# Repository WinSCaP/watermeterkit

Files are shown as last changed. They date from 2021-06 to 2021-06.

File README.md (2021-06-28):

# watermeterkit

> Maak je even een backup van je Wemos? :)
- Download https://github.com/espressif/esptool
- backup `.\esptool.exe --port COMx --baud 115200 read_flash 0x000 4194304 backup-watermeter.bin` (Eigen COM poort opgeven)
- restore `.\esptool.exe --port COMx --baud 115200 write_flash 0x000 backup-watermeter.bin`
- Heb je python? [espota.py](https://github.com/esp8266/Arduino/blob/master/tools/espota.py)
- `python espota.py -d -i 192.168.4.1 -f backup-watermeter.bin` (OTA, dus niet naar de meterkast om te flashen )

De watermeterkit kun je kopen via watermeterkit.nl. Deze is compleet met behuizing. Maar helaas is er ook een nadeel. De YAML is niet vrijgegeven, dus hij is defacto closed source. Maar daar kunnen we iets aan doen :)

## Ja en nu?
1. De YAML voor model A en model B vind je [hier](esphome)
2. Wil je een generieke [behuizing](mount)
3. Of gewoon de [home assistant config?](homeassistant)

### Kosten voor water in HA
Tarieven:
- [Dunea](https://www.dunea.nl/tarieven-en-voorwaarden)
- Pull requests welkom :)

## Reverse enginering Model B
- NPN Proximity Sensor LJ18A3-8-Z/BX-5V (https://nl.aliexpress.com/item/32844213899.html)
  - 5v Bruin
  - gnd blauw
  - data zwart (D5)
- WemosD1 (https://nl.aliexpress.com/item/32651747570.html)
- RGB Led (blauw niet aan Wemos)
  - D4 - Rood
  - D3 - Groen (zit ook aan standaard blauwe LED van Wemos)
  - Vervangen door Neopixel? (https://nl.aliexpress.com/item/32732638750.html)
- HDC1080 (temperature humidity) Component in ESPhome
  - Model A heeft een SHT
  - BME 280 toevoegen voor luchtdruk?
- Additioneel
  - Buzzer (Restant van Tagreader (https://github.com/adonno/tagreader) D7?

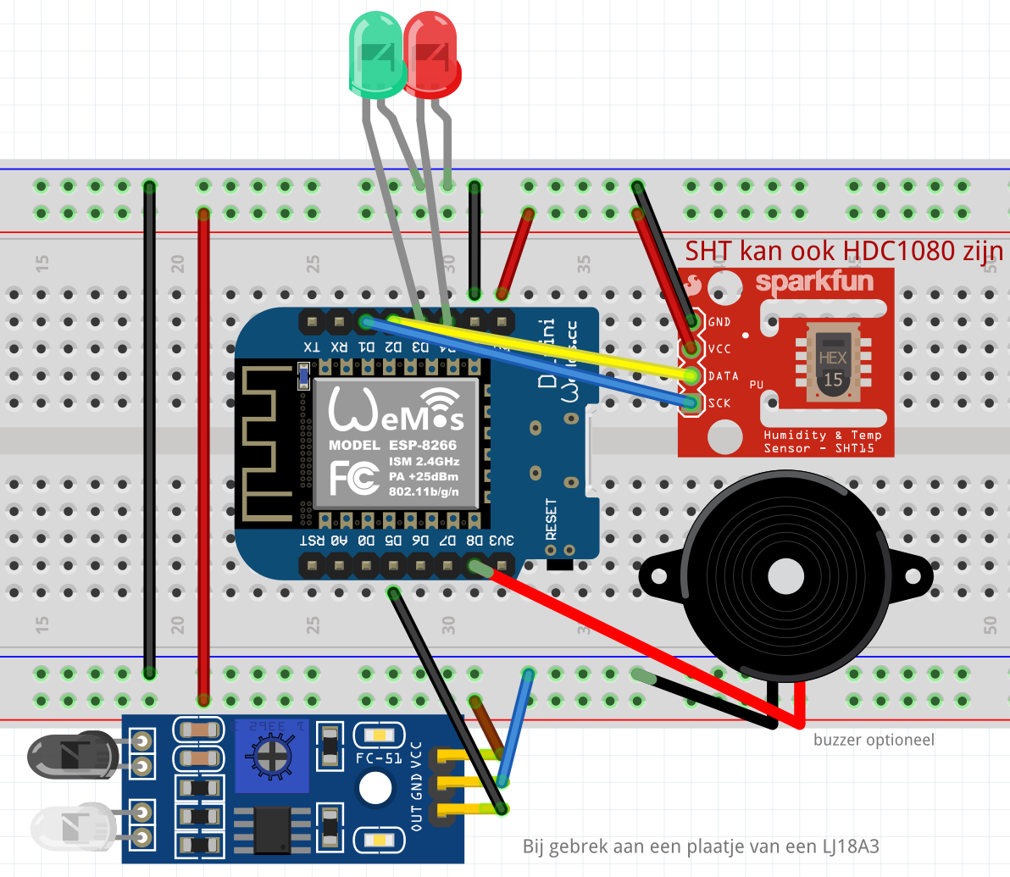
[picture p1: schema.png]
Schema


| | | Wemos  | | |
|---|---|---|---|---|
| |RST| |TX | |
| |A0| |RX | |
| |D0| |D1 |HDC1080 - SCL|
|Pulsemeter|D5| |D2 |HDC1080 - SDA|
| |D6| |D3 |Led G|
| |D7| |D4 |Led R|
| |D8| |GND| |
| |3v3| |5V| |

## Mounts
- Sensus 620 https://www.thingiverse.com/thing:4489072
- Generiek (In deze Repo)
- Kopen bij watermeterkit.nl
 
## Meuk
- https://www.jbswebcom.nl/knutselen/index.php/watermeter-uitlezen-met-npn-sensor
- https://community.home-assistant.io/t/inductive-npn-sensor-and-raspberry-pi/132487
- https://community.home-assistant.io/t/inductive-water-meter/144990/15
- https://esphome.io/components/sensor/pulse_counter.html
- https://gathering.tweakers.net/forum/list_messages/1596066/16
- https://www.huizebruin.nl/home-assistant/esphome/watermeter-uitlezen-in-home-assistant-met-esphome/
- https://github.com/frenck/home-assistant-config

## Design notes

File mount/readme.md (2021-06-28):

# Mount
Hier kun je een aantal mounts vinden. Maar ze zijn inferieur als het het vergelijkt met gewoon heel veel klitteband ;P

Ergo, koop even de watermeterkit.nl voor een behuizing die echt goed past.

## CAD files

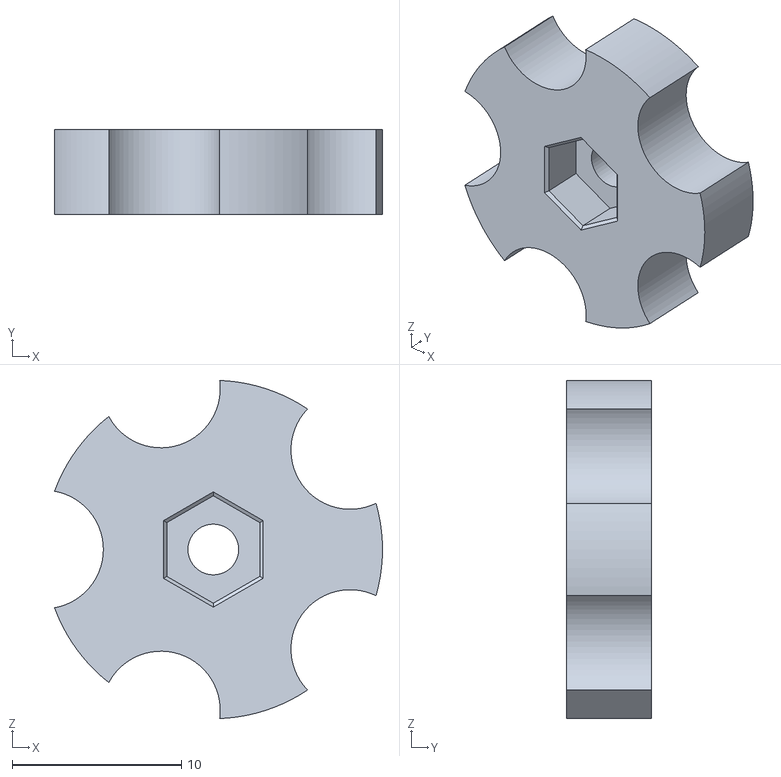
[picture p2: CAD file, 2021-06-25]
mount/knob_watermeter.stl
19.4 x 5.00 x 20.0

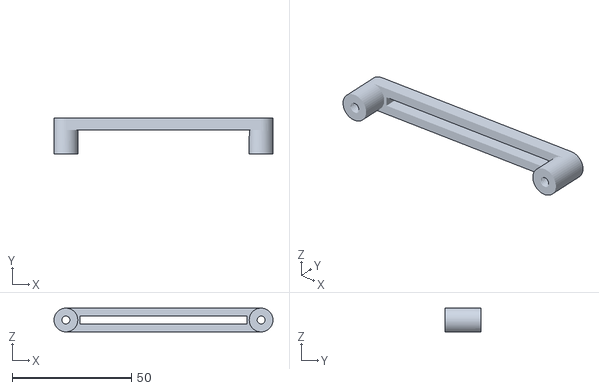
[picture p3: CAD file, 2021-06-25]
mount/basis_watermeter_onder.stl
92.0 x 15.0 x 10.0

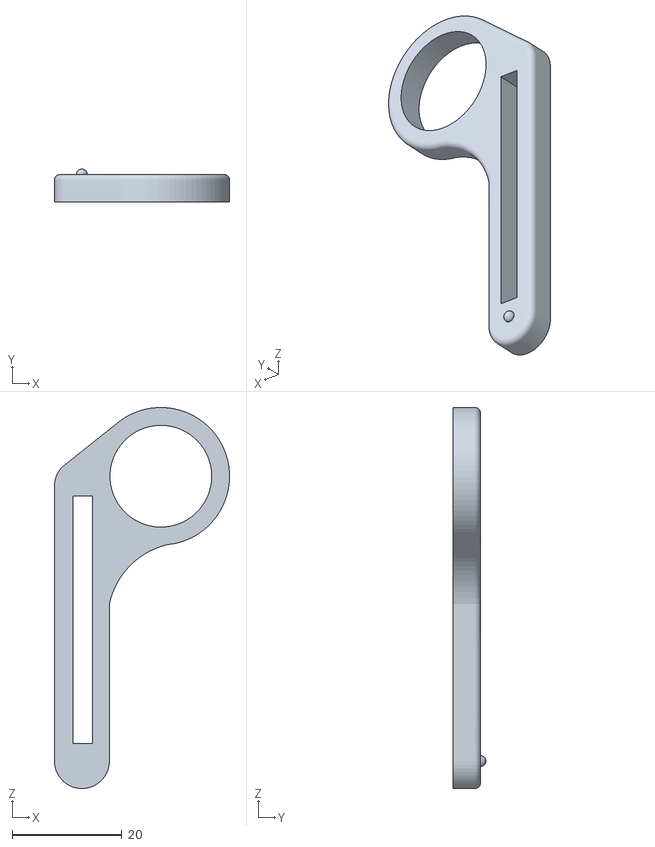
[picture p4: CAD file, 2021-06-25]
mount/basis_watermeter_boven.stl
31.9 x 6.00 x 69.3

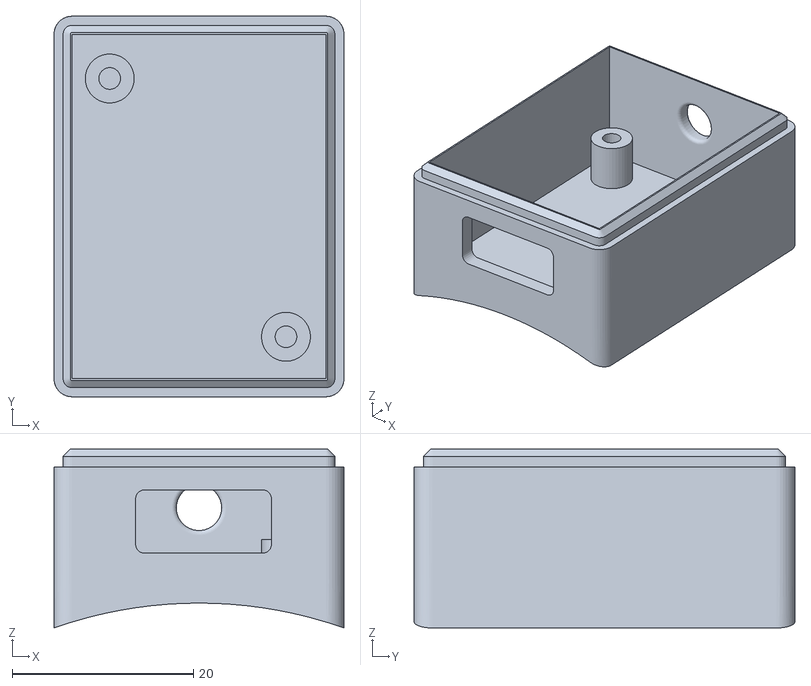
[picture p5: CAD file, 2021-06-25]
mount/case_watermeter_body.stl
32.0 x 42.0 x 19.7

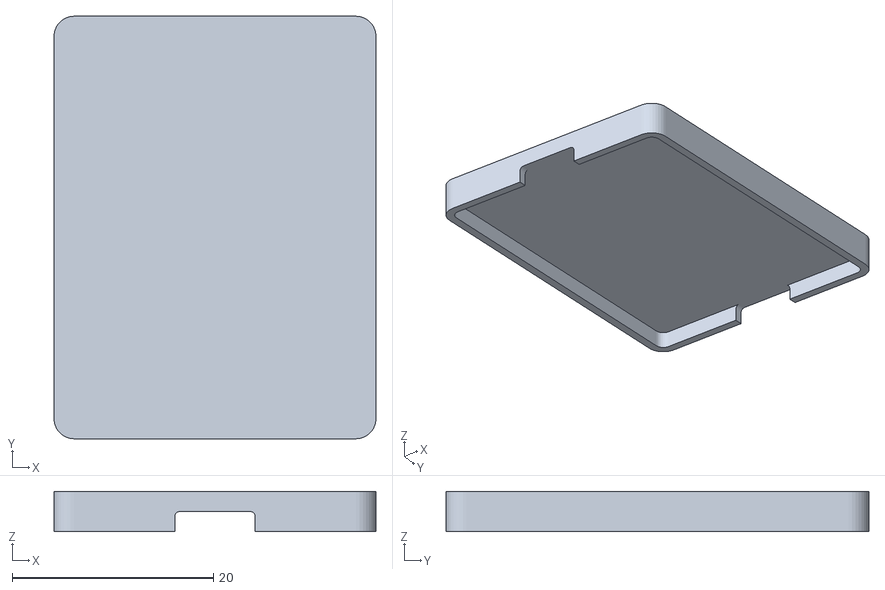
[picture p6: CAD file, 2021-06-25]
mount/case_watermeter_deksel.stl
32.0 x 42.0 x 4.00

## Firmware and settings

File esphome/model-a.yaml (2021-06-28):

---
# Water Meter
#
# Aggrigated from: https://github.com/frenck/home-assistant-config/blob/master/config/esphome/water_meter.yaml
# Modified to be compliant with the original
#
# This is device that is attached to my water meter. It has a little rotating
# indicator, that rotates exactly once for each liter of water used.
#
# Using an inductive sensor, it can determine the water usage, as each pulse
# now becomes a liter of water. Providing me current usage flow in L/min and
# the total usage registered (in M3).
#
# Originally bought on: https://watermeterkit.nl
# But created my own ESPHome firmware for it (which is what you are looking at).
#
# The blue LED tells the device is powered on (built-in on the Wemos D1 mini).
# The green LED blinks when a pulse is measures (each liter of water used).
# The red LED shows if there is a problem:
# - Blinks slow (once a second): Connection disrupted
# - Blinks fast: ESPHome has an error settings up
# - Off: All fine!
#
substitutions:
  slug: watermeter
  name: Water Meter
  description: "Small pulse sensor attached to the water meter of my home. Repo: https://github.com/WinSCaP/watermeterkit"
  api_password: !secret api_password
  ota_password: !secret api_password
  version: "1.1"
  model: model-a
  time_timezone: "Europe/Amsterdam"
  web_server_username: esphome
  web_server_password: !secret esphome_web_server_password  
  wifi_ssid: !secret wifi_ssid
  wifi_password: !secret wifi_password
  wifi_ap_password: "esphome-${slug}"

api:
  id: component_api
  password: "${api_password}"
  # Made this a bit longer, as in my case...
  # I F-things up from time to time, this gives me time to fix ;)
  reboot_timeout: 30min
captive_portal: 
logger:
  id: component_logger
  # Disabling logging over UART by default.
  # Some devices this is needed, and in general,
  # I really don't look at it.
#    baud_rate: 0  # Remove # to disable UART
ota:
  id: component_ota
  password: "${ota_password}"
  safe_mode: true
  reboot_timeout: 10min
  num_attempts: 5  
wifi:
  id: component_wifi
  ssid: "${wifi_ssid}"
  password: "${wifi_password}"
  reboot_timeout: 10min
  ap:
    ssid: "${name}"
    password: "${wifi_ap_password}"

esphome:
  name: "${slug}"
  comment: "${description}"
  build_path: "./.build/${slug}/"
  platform: ESP8266
  board: d1_mini
  on_boot:
    priority: -10
    then:
    - wait_until:
        api.connected:
    - logger.log: API is connected!
    - text_sensor.template.publish:
        id: template_model
        state: "${model}"
    - text_sensor.template.publish:
        id: template_version
        state: "${version}"
i2c:
  scl: D1
  sda: D2
  scan: True
  frequency: 50kHz

switch:
  - platform: restart
    id: switch_restart
    name: "${name} Restart"

status_led:
  pin: D3

output:
  - platform: esp8266_pwm
    id: output_led_green
    pin: D4

light:
  - platform: monochromatic
    id: light_led_green
    output: output_led_green

time:
  - platform: homeassistant
    id: time_homeassistant
    timezone: "${time_timezone}"
    on_time_sync:
      - component.update: sensor_uptime_timestamp
  - platform: sntp
    id: time_sntp
    timezone: "${time_timezone}"

web_server:
  id: component_web_server
  port: 80
  auth:
    username: "${web_server_username}"
    password: "${web_server_password}"

binary_sensor:
  - platform: status
    name: "${name} sensor"
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

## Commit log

2021-06-24 Aqaudis+ Dunea STL bestanden via Dwains
    [bodemplaat-wml_v27.stl, sensor-houder_18mm_v3.stl]
2021-06-25 Create sensor.yaml
    https://www.codepile.net/pile/kP3AQa5v
2021-06-26 Add files via upload
    Watermeter schema Fritzing
    [watermeter.fzz]
